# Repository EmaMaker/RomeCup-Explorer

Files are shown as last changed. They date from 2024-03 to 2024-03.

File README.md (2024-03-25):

# RomeCup Explorer

This repository contains the PCBs design files and code for the RomeCup Explorer playfield.

The RomeCup is a yearly event held by [Fondazione Mondo Digitale](https://mondodigitale.org) in
Rome, Italy, revolving around robotics and artificial intelligence. A big part of the event are the
robotics competitions aimed at middle and high school students. Some categories of competition are parallel to
the [RoboCup Junior](https://junior.robocup.org) (e.g. Soccer Open/LightWeight, Rescue Line), while
others are exclusive to RomeCup, like the Explorer category and, starting 2024, the Robotic Arms
category.

In the Explorer category, robots build and programmed by the students have to navigate a maze while
finding and recognizing different "hotspots". The hotspots can be of different kinds (in ascending
	order of points earned):

- Gas sources (1)
- Light source (2)
- Sound sources (3)

In 2024, we decided to rebuild the explorer category playfield from the ground up, favouring ease of
transport and assembly once on site (RomeCup is held every year at a different location, with the
	finals taking place in Rome Capitol every year).

To follow this route, we decided to have each hotspot have its own PCB to generate light and sound,
   instead of having a single source with cables running underneath the playfield. This also makes
   rearranging the maze easier in between rounds. In this repo, you can find the KiCad project files
   for the light and sound generation PCB, along side the BOM and manufacturing files for both
   standalone boards and panels, and the Arduino code powering the AtTiny412 microcontroller used in
   the sound boards. 

If you want to know more about the thought process and design decisions for the playfield, or about
the RoboCup 2024 event in general, I have written a [blog post](https://emamaker.com/events/romecup2024)
about it.

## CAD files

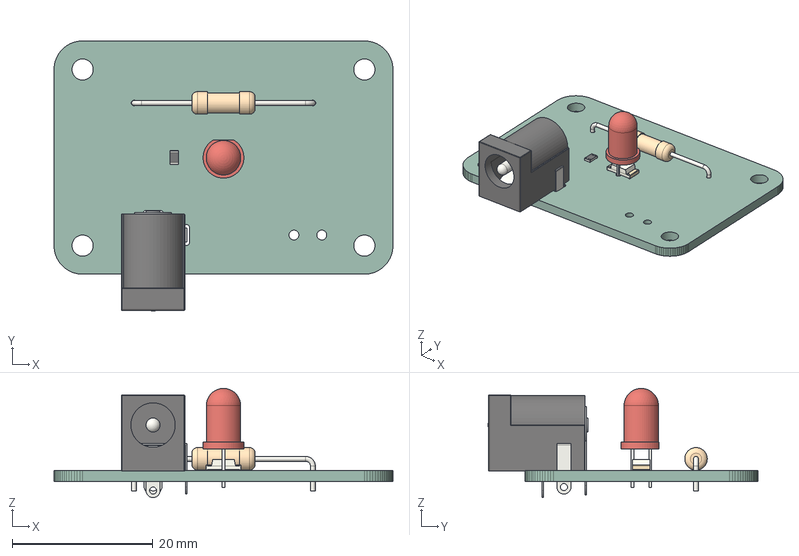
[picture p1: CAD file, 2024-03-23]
boards/explorer-light/explorer-light.step
48.1 x 38.4 x 15.5 mm
BarrelJack_Horizontal
LED_D5.0mm
LED_2010_5025Metric
R_Axial_DIN0309_L90mm_D32mm_P2540mm_Horizontal
R_0805_2012Metric
explorer-light PCB

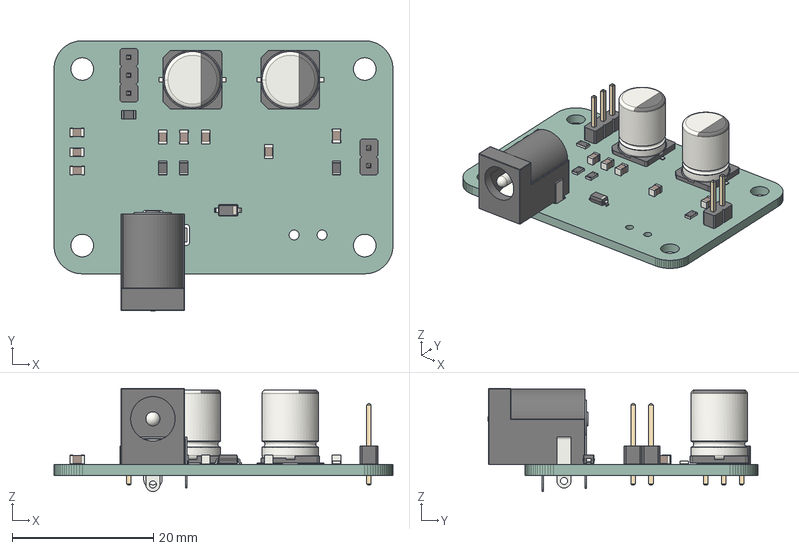
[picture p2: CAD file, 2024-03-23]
boards/explorer-sound/explorer.step
48.0 x 38.3 x 14.6 mm
R_0805_2012Metric x 4
C_0805_2012Metric x 8
BarrelJack_Horizontal
CP_Elec_8x105 x 2
PinHeader_1x02_P254mm_Vertical
D_SOD_123
PinHeader_1x03_P254mm_Vertical
explorer PCB

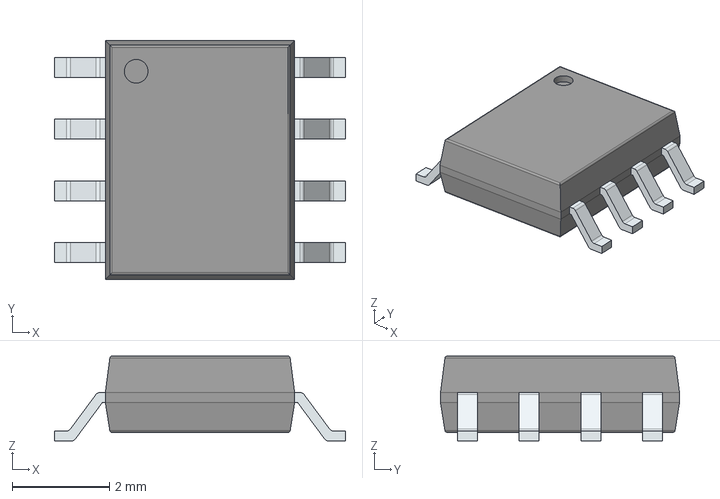
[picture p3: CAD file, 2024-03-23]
boards/explorer-sound/kicad-libs/LIB_ATTINY412-SSF/ATTINY412-SSF/3D/ATTINY412-SSF.stp
6.00 x 4.92 x 1.75 mm
PinsArrayLR

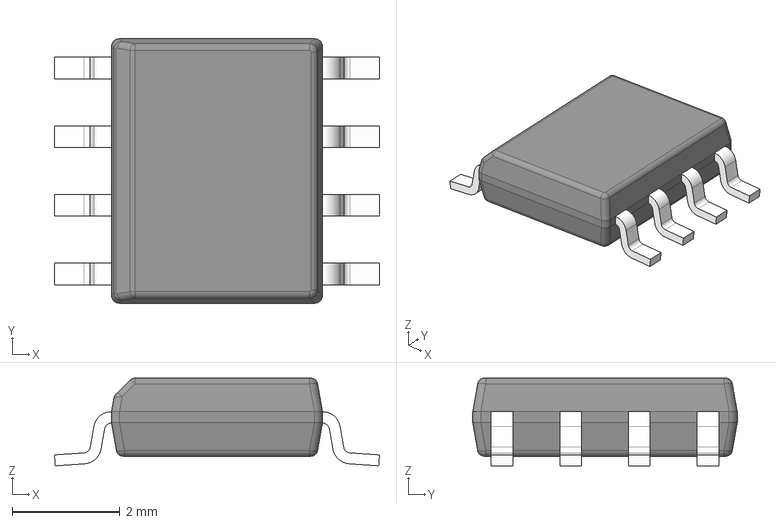
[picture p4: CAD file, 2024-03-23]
boards/explorer-sound/kicad-libs/LIB_LM386M-1_NOPB/LM386M-1_NOPB/3D/LM386M-1_NOPB.stp
6.02 x 4.90 x 1.63 mm
BODY-SO
LEAD-D0008A x 8

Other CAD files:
boards/explorer-sound/kicad-libs/LIB_ATTINY412-SSF/ATTINY412-SSF/Allegro/soic127p600x175-8n.psm
boards/explorer-sound/kicad-libs/LIB_ATTINY412-SSF/ATTINY412-SSF/DEHDL/attiny412_ssf/chips/chips.prt
boards/explorer-sound/kicad-libs/LIB_LM386M-1_NOPB/LM386M-1_NOPB/Allegro/soic127p600x175-8n.psm
boards/explorer-sound/kicad-libs/LIB_LM386M-1_NOPB/LM386M-1_NOPB/DEHDL/lm386m_1_nopb/chips/chips.prt

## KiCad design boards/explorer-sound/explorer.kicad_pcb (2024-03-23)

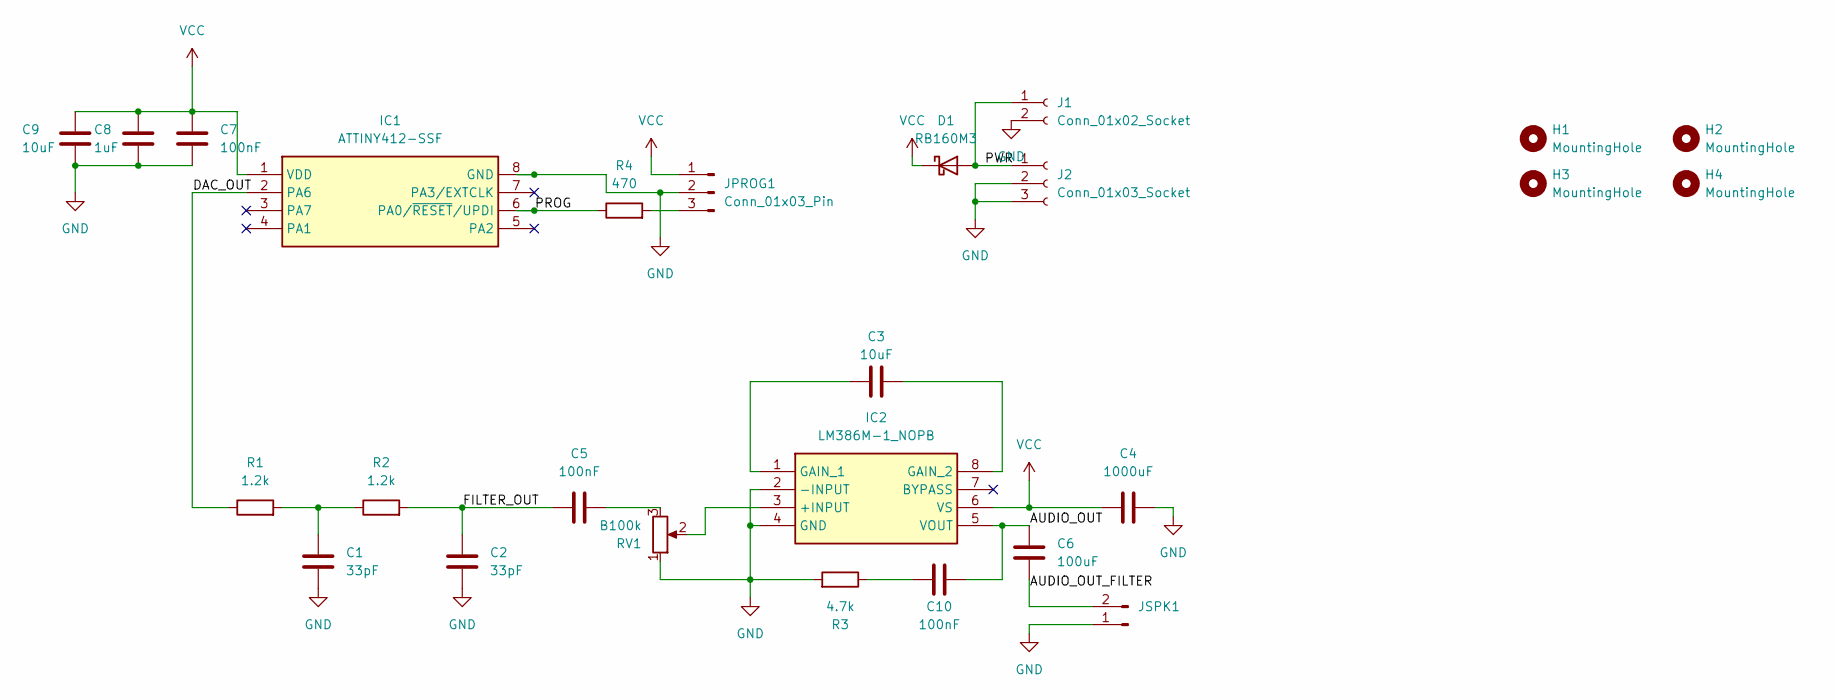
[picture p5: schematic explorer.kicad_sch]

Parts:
C1, C2: 33pF; C_0805_2012Metric_Pad1.18x1.45mm_HandSolder
C3, C9: 10uF; C_0805_2012Metric_Pad1.18x1.45mm_HandSolder
C4: 1000uF; CP_Elec_8x10.5
C5, C7, C10: 100nF; C_0805_2012Metric_Pad1.18x1.45mm_HandSolder
C6: 100uF; CP_Elec_8x10.5
C8: 1uF; C_0805_2012Metric_Pad1.18x1.45mm_HandSolder
D1: RB160M3; D_SOD-123
H1, H2, H3, H4: MountingHole; MountingHole_3.2mm_M3
IC1: ATTINY412-SSF; SOIC127P600X175-8N; Manufacturer_Part_Number ATTINY412-SSF; Mouser Part Number 579-ATTINY412-SSF
IC2: LM386M-1_NOPB; SOIC127P600X175-8N; Manufacturer_Part_Number LM386M-1/NOPB; Mouser Part Number 926-LM386M-1/NOPB
J1: Conn_01x02_Socket; TE_826576-2_1x02_P3.96mm_Vertical
J2: Conn_01x03_Socket; BarrelJack_Horizontal
JPROG1: Conn_01x03_Pin; PinHeader_1x03_P2.54mm_Vertical
JSPK1: Connector_PinHeader_2.54mm:PinHeader_1x02_P2.54mm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; PinHeader_1x02_P2.54mm_Vertical
R1, R2: 1.2k; R_0805_2012Metric_Pad1.20x1.40mm_HandSolder
R3: 4.7k; R_0805_2012Metric_Pad1.20x1.40mm_HandSolder
R4: 470; R_0805_2012Metric_Pad1.20x1.40mm_HandSolder
RV1: B100k; Potentiometer_Bourns_3214X_Vertical

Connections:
/AUDIO_OUT: C6.1, C10.2, IC2.5 (VOUT)
/AUDIO_OUT_FILTER: C6.2, JSPK1.2
/DAC_OUT: IC1.2 (PA6), R1.1
/FILTER_OUT: C2.1, C5.1, R2.2
/PROG: IC1.6 (PA0/~RESET/UPDI), R4.1
/PWR: D1.2 (A), J1.1, J2.1
GND: C1.2, C2.2, C4.2, C7.2, C8.2, C9.2, IC1.8 (GND), IC2.2 (-INPUT), IC2.4 (GND), J1.2, J2.2, J2.3, JPROG1.2, JSPK1.1, R3.2, RV1.1
unnamed: C1.1, R1.2, R2.1
unnamed: C5.2, RV1.3
unnamed: C10.1, R3.1
unnamed: IC2.3 (+INPUT), RV1.2
unnamed: C3.1, IC2.1 (GAIN_1)
unnamed: C3.2, IC2.8 (GAIN_2)
unnamed: JPROG1.3, R4.2
VCC: C4.1, C7.1, C8.1, C9.1, D1.1 (K), IC1.1 (VDD), IC2.6 (VS), JPROG1.1

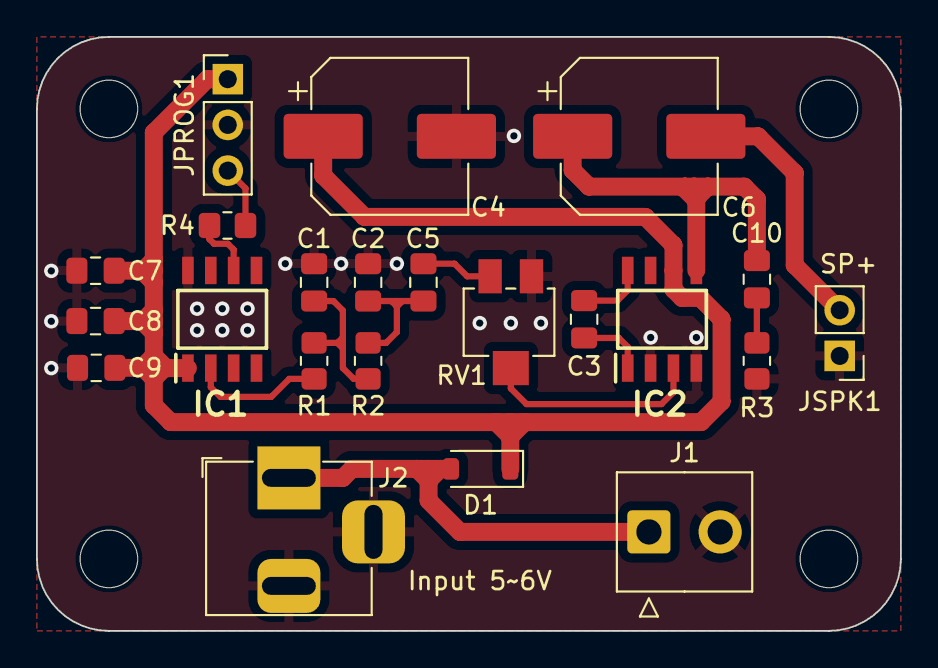
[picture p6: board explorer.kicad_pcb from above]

Board: 2 copper layers, 48.0 x 33.0 mm, 26 parts (0 on the bottom side), 15 nets.

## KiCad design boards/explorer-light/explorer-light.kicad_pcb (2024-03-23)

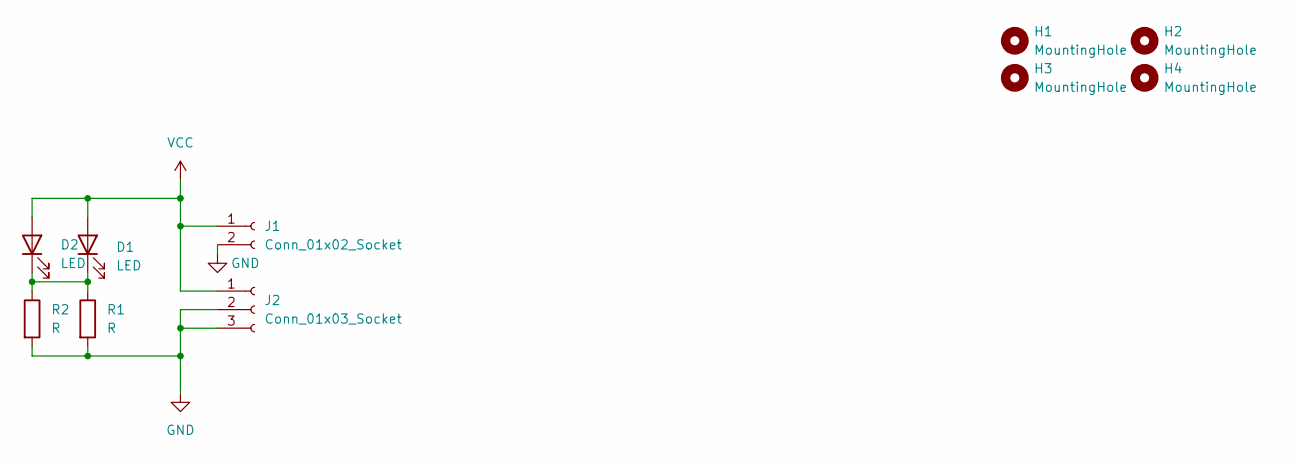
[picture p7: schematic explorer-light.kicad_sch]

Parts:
D1: LED; LED_2010_5025Metric_Pad1.52x2.65mm_HandSolder
D2: LED; LED_D5.0mm
H1, H2, H3, H4: MountingHole; MountingHole_3mm
J1: Conn_01x02_Socket; TE_826576-2_1x02_P3.96mm_Vertical
J2: Conn_01x03_Socket; BarrelJack_Horizontal
R1: R; R_Axial_DIN0309_L9.0mm_D3.2mm_P25.40mm_Horizontal
R2: R; R_0805_2012Metric_Pad1.20x1.40mm_HandSolder

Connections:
GND: J1.2, J2.2, J2.3, R1.2, R2.2
unnamed: D1.1 (K), D2.1 (K), R1.1, R2.1
VCC: D1.2 (A), D2.2 (A), J1.1, J2.1

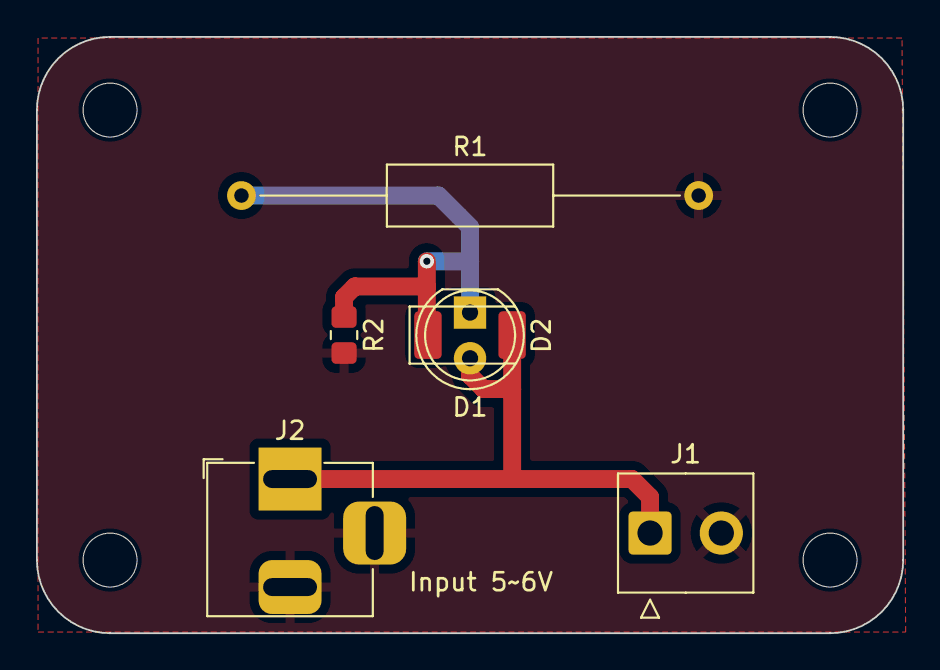
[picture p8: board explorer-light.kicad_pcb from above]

Board: 2 copper layers, 48.1 x 33.1 mm, 10 parts (0 on the bottom side), 3 nets.

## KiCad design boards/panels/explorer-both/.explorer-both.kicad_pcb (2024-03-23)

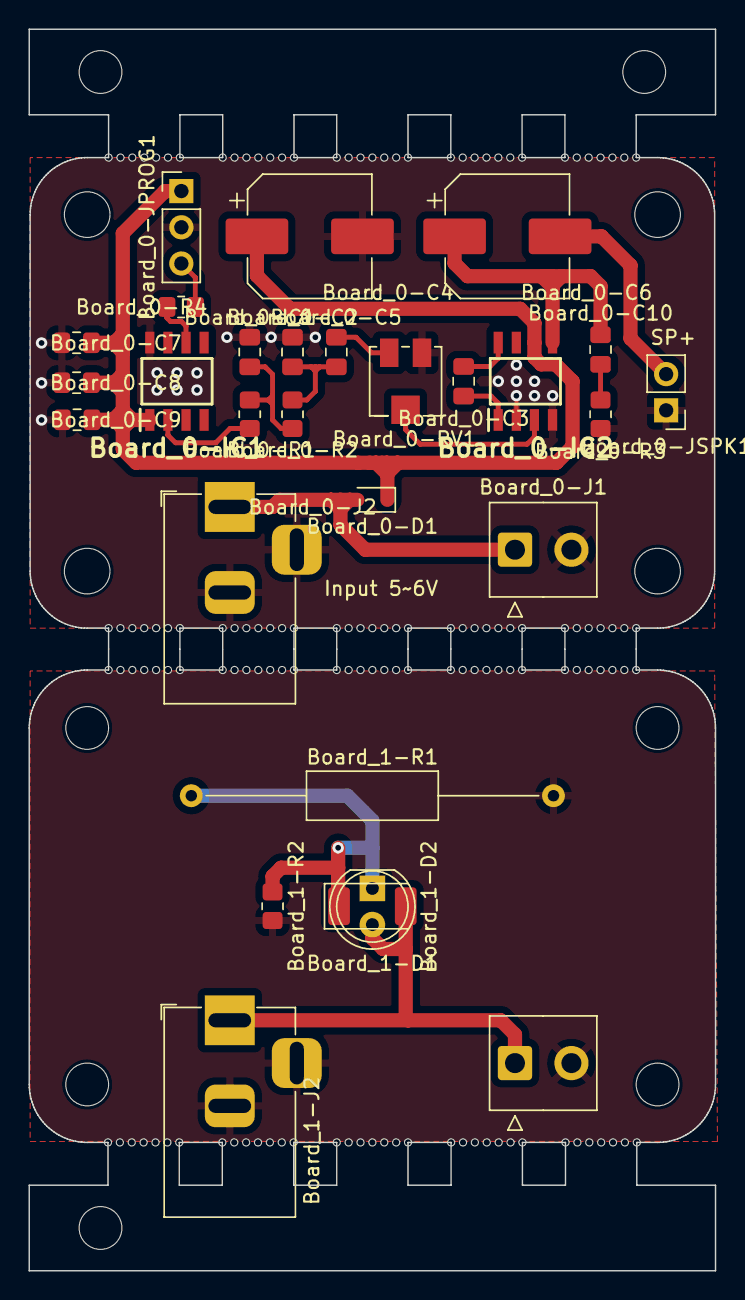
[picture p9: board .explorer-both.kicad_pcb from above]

Board: 2 copper layers, 48.1 x 87.1 mm, 179 parts (0 on the bottom side), 18 nets.

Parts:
Board_0-C1, Board_0-C2: 33pF; C_0805_2012Metric_Pad1.18x1.45mm_HandSolder
Board_0-C3, Board_0-C9: 10uF; C_0805_2012Metric_Pad1.18x1.45mm_HandSolder
Board_0-C4: 1000uF; CP_Elec_8x10.5
Board_0-C5, Board_0-C7, Board_0-C10: 100nF; C_0805_2012Metric_Pad1.18x1.45mm_HandSolder
Board_0-C6: 100uF; CP_Elec_8x10.5
Board_0-C8: 1uF; C_0805_2012Metric_Pad1.18x1.45mm_HandSolder
Board_0-D1: D_Schottky; D_SOD-323
Board_0-H1, Board_0-H2, Board_0-H3, Board_0-H4: MountingHole; MountingHole_3.2mm_M3
Board_0-IC1: ATTINY412-SSF; SOIC127P600X175-8N
Board_0-IC2: LM386M-1_NOPB; SOIC127P600X175-8N
Board_0-J1, Board_1-J1: Conn_01x02_Socket; TE_826576-2_1x02_P3.96mm_Vertical
Board_0-J2, Board_1-J2: Conn_01x03_Socket; BarrelJack_Horizontal
Board_0-JPROG1: Conn_01x03_Pin; PinHeader_1x03_P2.54mm_Vertical
Board_0-JSPK1: Connector_PinHeader_2.54mm:PinHeader_1x02_P2.54mm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; PinHeader_1x02_P2.54mm_Vertical
Board_0-R1, Board_0-R2: 1.2k; R_0805_2012Metric_Pad1.20x1.40mm_HandSolder
Board_0-R3: 4.7k; R_0805_2012Metric_Pad1.20x1.40mm_HandSolder
Board_0-R4: 470; R_0805_2012Metric_Pad1.20x1.40mm_HandSolder
Board_0-RV1: B100k; Potentiometer_Bourns_3214J_Horizontal
Board_1-D1: LED; LED_2010_5025Metric_Pad1.52x2.65mm_HandSolder
Board_1-D2: LED; LED_D5.0mm
Board_1-H1, Board_1-H2, Board_1-H3, Board_1-H4: MountingHole; MountingHole_3mm
Board_1-R1: R; R_Axial_DIN0309_L9.0mm_D3.2mm_P25.40mm_Horizontal
Board_1-R2: R; R_0805_2012Metric_Pad1.20x1.40mm_HandSolder
KiKit_MB_1_1, KiKit_MB_1_2, KiKit_MB_1_3, KiKit_MB_1_4, KiKit_MB_1_5, KiKit_MB_1_6, KiKit_MB_1_7, KiKit_MB_2_1, KiKit_MB_2_2, KiKit_MB_2_3, KiKit_MB_2_4, KiKit_MB_2_5, KiKit_MB_2_6, KiKit_MB_2_7, KiKit_MB_3_1, KiKit_MB_3_2, KiKit_MB_3_3, KiKit_MB_3_4, KiKit_MB_3_5, KiKit_MB_3_6, KiKit_MB_3_7, KiKit_MB_4_1, KiKit_MB_4_2, KiKit_MB_4_3, KiKit_MB_4_4, KiKit_MB_4_5, KiKit_MB_4_6, KiKit_MB_4_7, KiKit_MB_5_1, KiKit_MB_5_2, KiKit_MB_5_3, KiKit_MB_5_4, KiKit_MB_5_5, KiKit_MB_5_6, KiKit_MB_5_7, KiKit_MB_6_1, KiKit_MB_6_2, KiKit_MB_6_3, KiKit_MB_6_4, KiKit_MB_6_5, KiKit_MB_6_6, KiKit_MB_6_7, KiKit_MB_7_1, KiKit_MB_7_2, KiKit_MB_7_3, KiKit_MB_7_4, KiKit_MB_7_5, KiKit_MB_7_6, KiKit_MB_7_7, KiKit_MB_8_1, KiKit_MB_8_2, KiKit_MB_8_3, KiKit_MB_8_4, KiKit_MB_8_5, KiKit_MB_8_6, KiKit_MB_8_7, KiKit_MB_9_1, KiKit_MB_9_2, KiKit_MB_9_3, KiKit_MB_9_4, KiKit_MB_9_5, KiKit_MB_9_6, KiKit_MB_9_7, KiKit_MB_10_1, KiKit_MB_10_2, KiKit_MB_10_3, KiKit_MB_10_4, KiKit_MB_10_5, KiKit_MB_10_6, KiKit_MB_10_7, KiKit_MB_11_1, KiKit_MB_11_2, KiKit_MB_11_3, KiKit_MB_11_4, KiKit_MB_11_5, KiKit_MB_11_6, KiKit_MB_11_7, KiKit_MB_12_1, KiKit_MB_12_2, KiKit_MB_12_3, KiKit_MB_12_4, KiKit_MB_12_5, KiKit_MB_12_6, KiKit_MB_12_7, KiKit_MB_13_1, KiKit_MB_13_2, KiKit_MB_13_3, KiKit_MB_13_4, KiKit_MB_13_5, KiKit_MB_13_6, KiKit_MB_13_7, KiKit_MB_14_1, KiKit_MB_14_2, KiKit_MB_14_3, KiKit_MB_14_4, KiKit_MB_14_5, KiKit_MB_14_6, KiKit_MB_14_7, KiKit_MB_15_1, KiKit_MB_15_2, KiKit_MB_15_3, KiKit_MB_15_4, KiKit_MB_15_5, KiKit_MB_15_6, KiKit_MB_15_7, KiKit_MB_16_1, KiKit_MB_16_2, KiKit_MB_16_3, KiKit_MB_16_4, KiKit_MB_16_5, KiKit_MB_16_6, KiKit_MB_16_7, KiKit_MB_17_1, KiKit_MB_17_2, KiKit_MB_17_3, KiKit_MB_17_4, KiKit_MB_17_5, KiKit_MB_17_6, KiKit_MB_17_7, KiKit_MB_18_1, KiKit_MB_18_2, KiKit_MB_18_3, KiKit_MB_18_4, KiKit_MB_18_5, KiKit_MB_18_6, KiKit_MB_18_7, KiKit_MB_19_1, KiKit_MB_19_2, KiKit_MB_19_3, KiKit_MB_19_4, KiKit_MB_19_5, KiKit_MB_19_6, KiKit_MB_19_7, KiKit_MB_20_1, KiKit_MB_20_2, KiKit_MB_20_3, KiKit_MB_20_4, KiKit_MB_20_5, KiKit_MB_20_6, KiKit_MB_20_7: NPTH
KiKit_TO_1, KiKit_TO_2, KiKit_TO_3: NPTH

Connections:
Board_0-/AUDIO_OUT: Board_0-C6.1, Board_0-C10.2, Board_0-IC2.5 (VOUT)
Board_0-/AUDIO_OUT_FILTER: Board_0-C6.2, Board_0-JSPK1.2
Board_0-/DAC_OUT: Board_0-IC1.2 (PA6), Board_0-R1.1
Board_0-/FILTER_OUT: Board_0-C2.1, Board_0-C5.1, Board_0-R2.2
Board_0-/PROG: Board_0-IC1.6 (PA0/~RESET/UPDI), Board_0-R4.1
Board_0-/PWR: Board_0-D1.2 (A), Board_0-J1.1, Board_0-J2.1
Board_0-GND: Board_0-C1.2, Board_0-C2.2, Board_0-C4.2, Board_0-C7.2, Board_0-C8.2, Board_0-C9.2, Board_0-IC1.8 (GND), Board_0-IC2.2 (-INPUT), Board_0-IC2.4 (GND), Board_0-J1.2, Board_0-J2.2, Board_0-J2.3, Board_0-JPROG1.2, Board_0-JSPK1.1, Board_0-R3.2, Board_0-RV1.3
Board_0-Net-(C1-Pad1): Board_0-C1.1, Board_0-R1.2, Board_0-R2.1
Board_0-Net-(C5-Pad2): Board_0-C5.2, Board_0-RV1.1
Board_0-Net-(C10-Pad1): Board_0-C10.1, Board_0-R3.1
Board_0-Net-(IC2-+INPUT): Board_0-IC2.3 (+INPUT), Board_0-RV1.2
Board_0-Net-(IC2-GAIN_1): Board_0-C3.1, Board_0-IC2.1 (GAIN_1)
Board_0-Net-(IC2-GAIN_2): Board_0-C3.2, Board_0-IC2.8 (GAIN_2)
Board_0-Net-(JPROG1-Pin_3): Board_0-JPROG1.3, Board_0-R4.2
Board_0-VCC: Board_0-C4.1, Board_0-C7.1, Board_0-C8.1, Board_0-C9.1, Board_0-D1.1 (K), Board_0-IC1.1 (VDD), Board_0-IC2.6 (VS), Board_0-JPROG1.1
Board_1-GND: Board_1-J1.2, Board_1-J2.2, Board_1-J2.3, Board_1-R1.2, Board_1-R2.2
Board_1-Net-(D1-K): Board_1-D1.1 (K), Board_1-D2.1 (K), Board_1-R1.1, Board_1-R2.1
Board_1-VCC: Board_1-D1.2 (A), Board_1-D2.2 (A), Board_1-J1.1, Board_1-J2.1

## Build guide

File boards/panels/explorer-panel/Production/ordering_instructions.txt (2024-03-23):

Ordering Instructions:
Panel dimensions: 98.26 x 136.63 mm.
Solder Mask: Red (Default)
Silkscreen: White (Default)
Layers: 2
Finish: HASL Lead-free (Default)
Thickness: 1.6mm (Default)
Copper weight: 1oz (Default)
Minimum track width: 0.30mm (11.81mil)

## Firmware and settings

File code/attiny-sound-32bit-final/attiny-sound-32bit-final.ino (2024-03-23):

// Able to achieve precise 4kHz with AtTiny clocking at 20MHz, LUT_SIZE = 32
// dreg needs to be calculated as shown in the paper and then fiddled with by hand, as I really do not know what Fs actually is
// Going lower than LUT_SIZE=32 makes the oscilloscope "lose" the trigger point more easily, but is still stable in frequency. A lower LUT_SIZE has the advantage of being easier to tune by hand, but admitingly once you establish a baseline for dreg, using simple proportions to tune the value exactly is not a problem
// Using this snippet I calculated Fsample (the frequency with which a generation cycle is executed) to be 1Mhz
// It outputs a triangle wave, Fsample is the inverse of an half period (double the frequency of the wave), since a cycle computes the rising edge and the following computes the falling edge
/*
// increment phase
phase_accumulator += dreg;
t = SINE_LUT[(phase_accumulator >> 8) & 0x7F];
DAC0.DATA = t1;
t1 = 255 -t1;  
*/

// AtTiny412 running at 20MHz

// https://www.nxp.com/docs/en/application-note/AN1771.pdf

// Not all AtTiny's reach exactly 4khz, because of the granularity (as explained in the article) of the decimal part.
// My solution: use a 4byte integer instead of a 2 byte one, use a single byte for the integer part and 3 bytes for the decimal part
// I limited the decimal part to 1 byte since the AtTiny only has 256B of RAM, the LUT is in RAM, and a 128B LUT is the biggest I can fit in memory while still using power of two

// try to keep LUT_SIZE to a power of two, so that the masking can be done efficiently
constexpr uint8_t LUT_SIZE = 32;
constexpr uint8_t LUT_MASK = LUT_SIZE - 1;
constexpr uint8_t LUT_SIZE_HALF = LUT_SIZE*0.5;
constexpr uint8_t LUT_SIZE_QUARTER = LUT_SIZE*0.25;
constexpr uint8_t MAX_VALUE = 255;

uint8_t SINE_LUT[LUT_SIZE];

// Delta = (LUT_SIZE * FREQ) / SAMPLE_FREQ
// Assume SAMPLE_FREQ 2.26khz
// Delta = 128 * 4000 / 1000000 = 0.512
// Integer part = 0 mask 0x0
// Decimal part = 0.512slightly
// 0.512 * 2^24 = 8589934.592, round to 8589935, mask 0x8589935 (calculated with gnome calc)

// by hand, slightly different than calculated (0x83)
uint32_t dreg = 0x42EACB;

uint32_t phase_accumulator = 0;

void setup() {  
  DACReference(INTERNAL4V3);
  noInterrupts();
  
  for (uint8_t i = 0; i < LUT_SIZE; i++) {
    // For the first quarter of the lut, generate a quarter of a sine wave
    if(i >= 0 && i <= LUT_SIZE_QUARTER) SINE_LUT[i] = (0.5f + 0.5f*sin((2 * PI * (float)i) / LUT_SIZE)) * MAX_VALUE;
    // For the second quarter, mirror the first quarter along the y axis
    else if(i > LUT_SIZE_QUARTER && i <= LUT_SIZE_HALF) SINE_LUT[i] = SINE_LUT[(LUT_SIZE_HALF-i)];
    // For the second half, mirror the first half along the x axis
    else SINE_LUT[i] = MAX_VALUE-SINE_LUT[(LUT_SIZE-i)];
  }

  // From megatinycore analogWrite(PIN_PA6)
  DAC0.CTRLA |= 0x41;
  while(1){
        // increment phase. We do not care about overflowing, it's actually beneficial because with can discard the carry bit and wrap back to zero, and start again from the beginning of the LUT without using if statements
        phase_accumulator += dreg;

        // Output to DAC
        // Shift to the right to extract the integer portion, mask the first 4 bits (size of LUT)        
        DAC0.DATA = SINE_LUT[(phase_accumulator >> 24) & LUT_MASK];
  }

}

void loop() {
}

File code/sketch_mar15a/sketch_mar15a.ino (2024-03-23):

// AtTiny412
// 16Mhz tuned following https://github.com/SpenceKonde/megaTinyCore/blob/master/megaavr/extras/Ref_Tuning.md
// millis/micros disabled

#include <Arduino.h>

constexpr uint8_t LUT_SIZE = 24;
constexpr uint8_t LUT_SIZE_HALF = LUT_SIZE*0.5;
constexpr uint8_t LUT_SIZE_QUARTER = LUT_SIZE*0.25;
constexpr uint8_t MAX_VALUE = 64;

constexpr float SAMPLE_FREQ = 57500.0;

uint8_t SINE_LUT[LUT_SIZE];

//constexpr float delta_phi = 4000.0f / SAMPLE_FREQ * (float)LUT_SIZE;
constexpr float delta_phi = 0.07052234f * (float)LUT_SIZE;
float phase = 0;

// constexpr uint8_t ddelta_phi = 0.05465 * LUT_SIZE;
// uint8_t phase = 0;

void setup() {
  DACReference(INTERNAL4V3);

  for (uint8_t i = 0; i < LUT_SIZE; i++) {
    // SINE_LUT[i] = (0.5f + 0.5*sin((2 * PI * (float)i) / LUT_SIZE)) * MAX_VALUE;

    //For the first quarter of the lut, generate a quarter of a sine wave
    if(i >= 0 && i <= LUT_SIZE_QUARTER) SINE_LUT[i] = (0.5f + 0.5*sin((2 * PI * (float)i) / LUT_SIZE)) * MAX_VALUE; // (uint8_t) (MAX_VALUE_HALF + (MAX_VALUE_HALF-1) * sin((2 * PI * (float)i) / LUT_SIZE));
    else if(i > LUT_SIZE_QUARTER && i <= LUT_SIZE_HALF) SINE_LUT[i] = SINE_LUT[(LUT_SIZE_HALF-i)];
    else SINE_LUT[i] = MAX_VALUE-SINE_LUT[(LUT_SIZE-i)];
  }

  DAC0.CTRLA |= 0x41;
  while(1){      
   
    phase += delta_phi;
    // handle wraparound           
    if (phase >= LUT_SIZE) phase -= LUT_SIZE;
    DAC0.DATA = SINE_LUT[(uint8_t)phase];
  }

}

void loop() {
}

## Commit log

2024-03-23 add light station pcb project+gerber
    [explorer-light-CuBottom.gbr, explorer-light-CuTop.gbr, explorer-light-EdgeCuts.gbr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]
2024-03-23 add sound station pcb project+gerber
    [ATTINY412-SSF.SchLib, ATTINY412-SSF.stp, EDI2CAP.CFG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]
2024-03-23 add projects for panels
    [.explorer-both.kicad_pcb, explorer-both.kicad_pcb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]
2024-03-23 add code for sound board. Use attiny-sound-32bit-final
